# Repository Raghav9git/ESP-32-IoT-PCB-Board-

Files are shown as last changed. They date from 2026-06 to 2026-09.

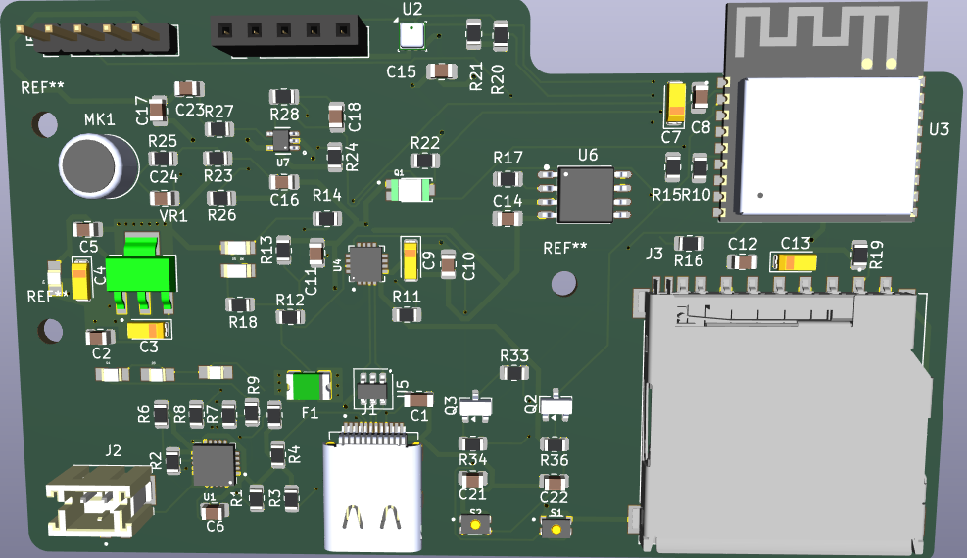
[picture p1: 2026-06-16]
3D view.png

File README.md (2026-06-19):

## ESP32-C3 IoT Sensor Development Board

A compact 4-layer IoT development board built around the ESP32-C3, integrating environmental sensing, local storage, USB-C power with LiPo battery management, and a programming/debug interface on a single board. Designed in KiCad 10.0.

This is a multi-domain hardware project that brings power electronics, mixed-signal sensor front-ends, digital interfaces, and RF-module integration together on one board — and routes them on a 4-layer stackup with dedicated power and ground planes.

## Overview

The goal of this board is a self-contained, battery-capable IoT platform: an ESP32-C3 (Wi-Fi + BLE) as the brain, surrounded by the supporting subsystems a real IoT device needs — clean regulated power, safe battery charging, local data storage, environmental sensors, and a robust USB programming path.

It was built as a deliberate skill-development project to practice end-to-end PCB design across several engineering domains in a single, non-trivial board, rather than a series of isolated single-function boards.

## Features

MCU: ESP32-C3-WROOM-02 module — Wi-Fi + Bluetooth LE
Power input: USB-C connector (power + data), with input fuse protection
Battery: LiPo battery connector with onboard charge management (MCP73871) and power-path control
Regulation: 3.3 V LDO (LM1117) for the logic rail, sourced from the 5 V USB rail
Programming/Debug: CP2102N USB-to-UART bridge with automatic boot/reset (DTR/RTS) circuit
Storage: microSD card slot (SPI) + onboard SPI flash (W25Q32)
Sensors:

BME280 — temperature, humidity, barometric pressure
TEMT6000 — ambient light
Electret microphone + MAX4466 pre-amplifier — audio/sound level

User interface: Boot and Reset buttons (with RC debounce), status LEDs, I²C OLED display header, GPIO breakout header
Debug: Test points on key SPI/SD signals
Protection: USB data-line ESD protection (USBLC6)
PCB: 4-layer design with dedicated power and ground planes

## Tech Specs

ItemDetailMicrocontrollerESP32-C3-WROOM-02 (Wi-Fi + BLE)PCB layers4 (signal / GND plane / power plane / signal)Power inputUSB-C (5 V) and LiPo batteryLogic rail3.3 V (LM1117 LDO)ChargingMCP73871 LiPo charger / power pathUSB–UART bridgeCP2102NStoragemicroSD (SPI) + W25Q32 SPI flashSensorsBME280, TEMT6000, MAX4466 mic ampInterfacesI²C, SPI, UART, GPIO headerDesign toolKiCad 10.0

## Subsystem Architecture

The board is organized as a set of interacting subsystems. Each block exists for a specific reason:

## Power & Battery Management

USB-C delivers 5 V, passed through a fuse for input protection. The MCP73871 handles LiPo charging and automatic power-path switching between USB power and battery, so the board runs from USB when connected and from battery otherwise. The LM1117 LDO derives the clean 3.3 V logic rail from the 5 V rail. Input and output decoupling capacitors sit close to the regulator for stability.

## MCU

The ESP32-C3-WROOM-02 is the core — a single-chip Wi-Fi + BLE module. It runs from the 3.3 V rail with local decoupling, and exposes the SPI, I²C, UART, and GPIO interfaces that connect to the rest of the board.

## Programming & Auto-Reset

A CP2102N USB-to-UART bridge provides the serial programming/debug interface over USB-C. The DTR/RTS auto-reset circuit (two transistors) automatically drives the EN and BOOT lines during flashing, so firmware can be uploaded without manually pressing buttons — the standard ESP programming convenience circuit. USBLC6 ESD protection guards the USB data lines.

## Storage

A microSD slot (SPI) provides removable local storage for data logging, and an onboard W25Q32 SPI flash offers fixed storage for configuration or firmware data. Test points on the SPI/SD lines allow probing during bring-up.

## Sensors (Mixed-Signal Front-Ends)

BME280 — digital environmental sensor (temperature, humidity, pressure) on the I²C/SPI bus.
TEMT6000 — analog ambient light sensor feeding an ADC input.
Electret mic + MAX4466 — an analog audio front-end; the MAX4466 amplifies the microphone signal to a usable level for the ADC.

The analog sensor front-ends are the mixed-signal portion of the design, where layout and grounding affect signal quality.

## User Interface

Boot and Reset buttons with RC debounce, status LEDs for power/operation indication, an I²C header for an OLED display, and a GPIO breakout header for expansion.

## Design Highlights

4-layer stackup with dedicated ground and power planes for clean power distribution and a solid low-impedance ground return — important on a board mixing RF, analog sensors, and digital interfaces.
Mixed-signal layout — separating noisy digital and switching activity from the analog sensor front-ends.
USB & ESD considerations — controlled USB data routing and dedicated ESD protection.
Net classes for differentiated trace widths (power vs. signal).
Test points on key debug nets for hardware bring-up.
Compact, thoughtful component placement following the power and signal flow.

## Project Status

~80% complete.

 Multi-page hierarchical schematic — complete, ERC passing
 Footprint assignment
 Component placement
 4-layer stackup and plane setup
 Routing (power and signal)
 Copper zones / ground pour
 Final silkscreen pass (labels, polarity marks, board info)
 Final DRC sign-off
 Manufacturing output (Gerbers / drill files)
 Fabrication and bring-up testing

Remaining work is finishing/polish: silkscreen cleanup, a final DRC pass, and generating manufacturing files.

## Skills Developed

This project was built to practice the full PCB workflow on a realistic, multi-domain board:

Multi-page hierarchical schematic design
Power electronics: LDO regulation, LiPo charge management, power-path design
Mixed-signal design: analog sensor front-ends alongside digital interfaces
RF module integration: ESP32-C3 placement and supporting circuitry
Digital interfaces: SPI (flash, SD), I²C (sensors, OLED), UART (programming)
USB & ESD: USB-C, USB-to-UART bridge, data-line protection
4-layer PCB layout: stackup, dedicated power/ground planes, copper zones
Net classes, trace-width selection, and DRC-driven debugging
Reading and applying datasheets for component configuration

## Tools

KiCad 10.0 — schematic capture and PCB layout
Component symbols, footprints, and 3D models sourced from KiCad libraries and standard component vendors

## References & Acknowledgments

This board was built as a learning project to develop hands-on PCB design skills across power, mixed-signal, and digital domains. The design follows and adapts a published KiCad IoT development-board reference/tutorial as a starting point, which I used to study how a complete, multi-subsystem board is architected, laid out on four layers, and prepared for manufacturing.

License

Released under the MIT License. See LICENSE for details.

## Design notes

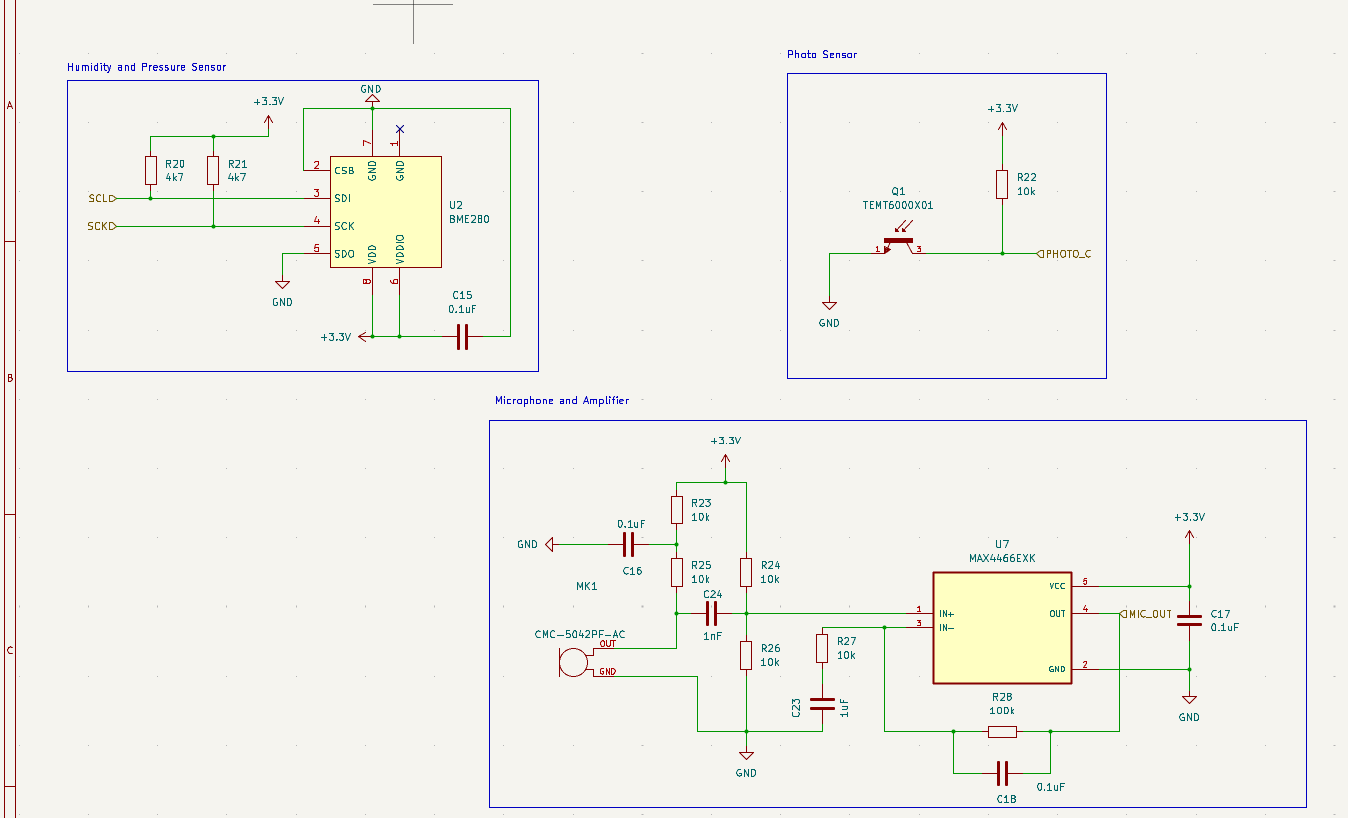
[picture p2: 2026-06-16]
Sensors.png

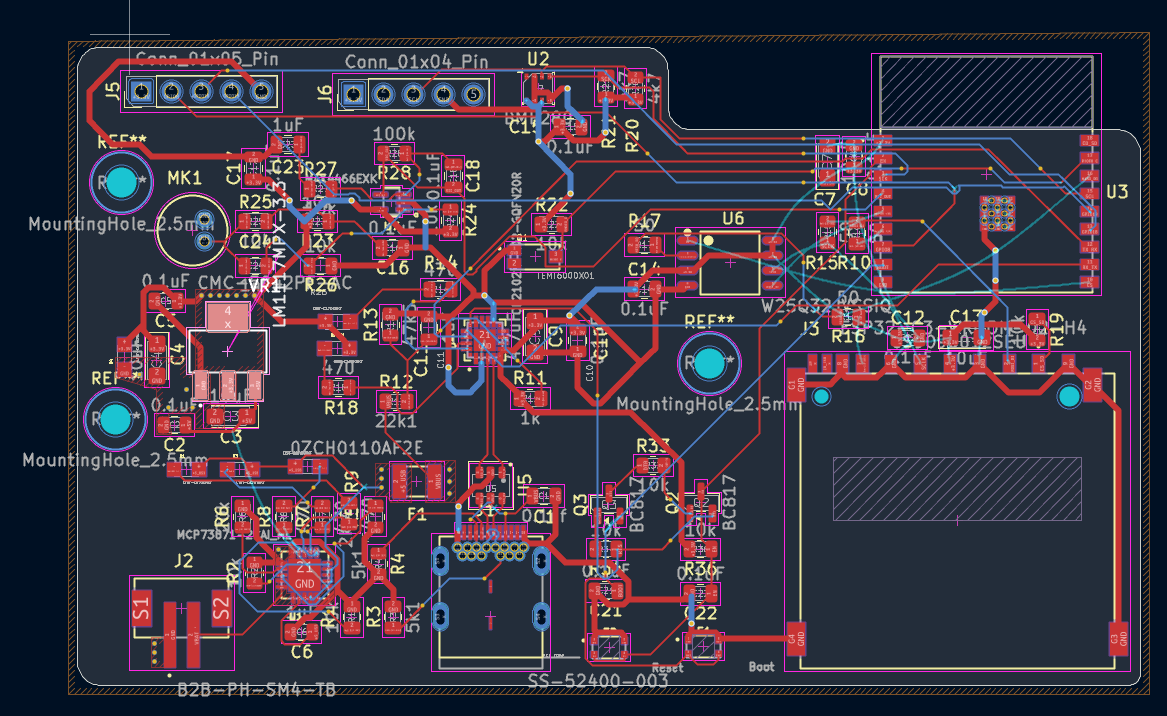
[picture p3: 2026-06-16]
PCB layout.png

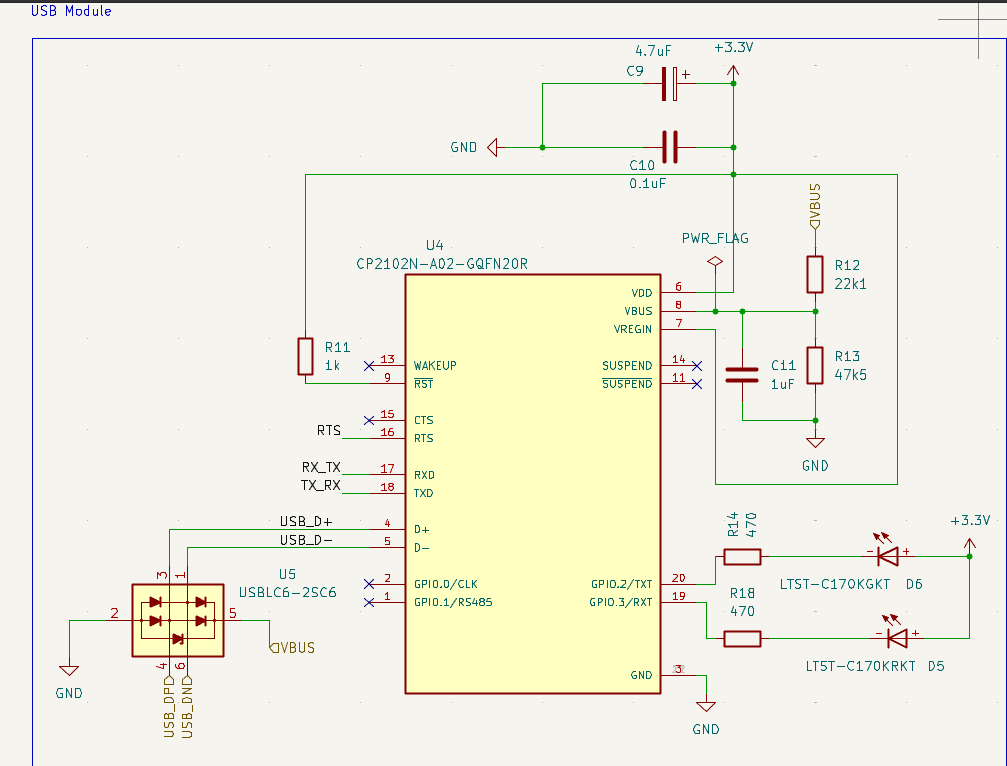
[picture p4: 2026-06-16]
Type C USB.png

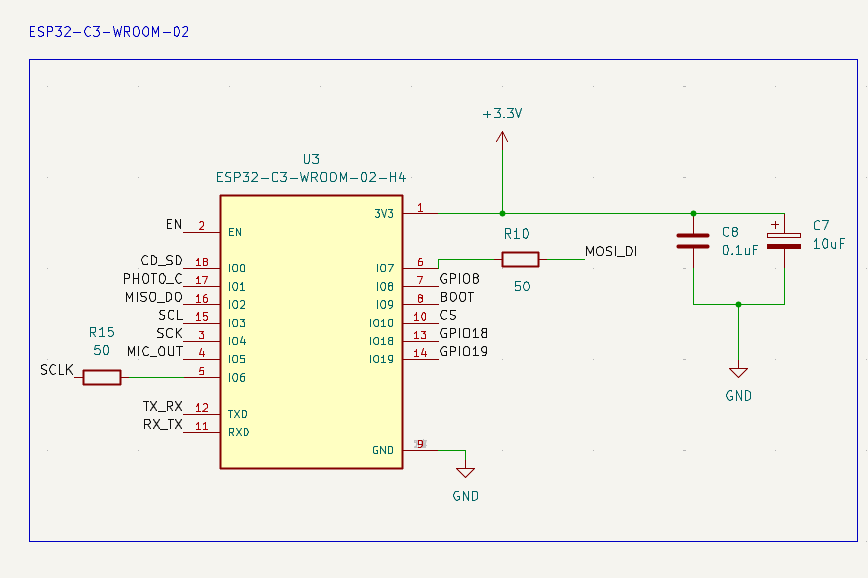
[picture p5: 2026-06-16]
ESP-32 Module.png

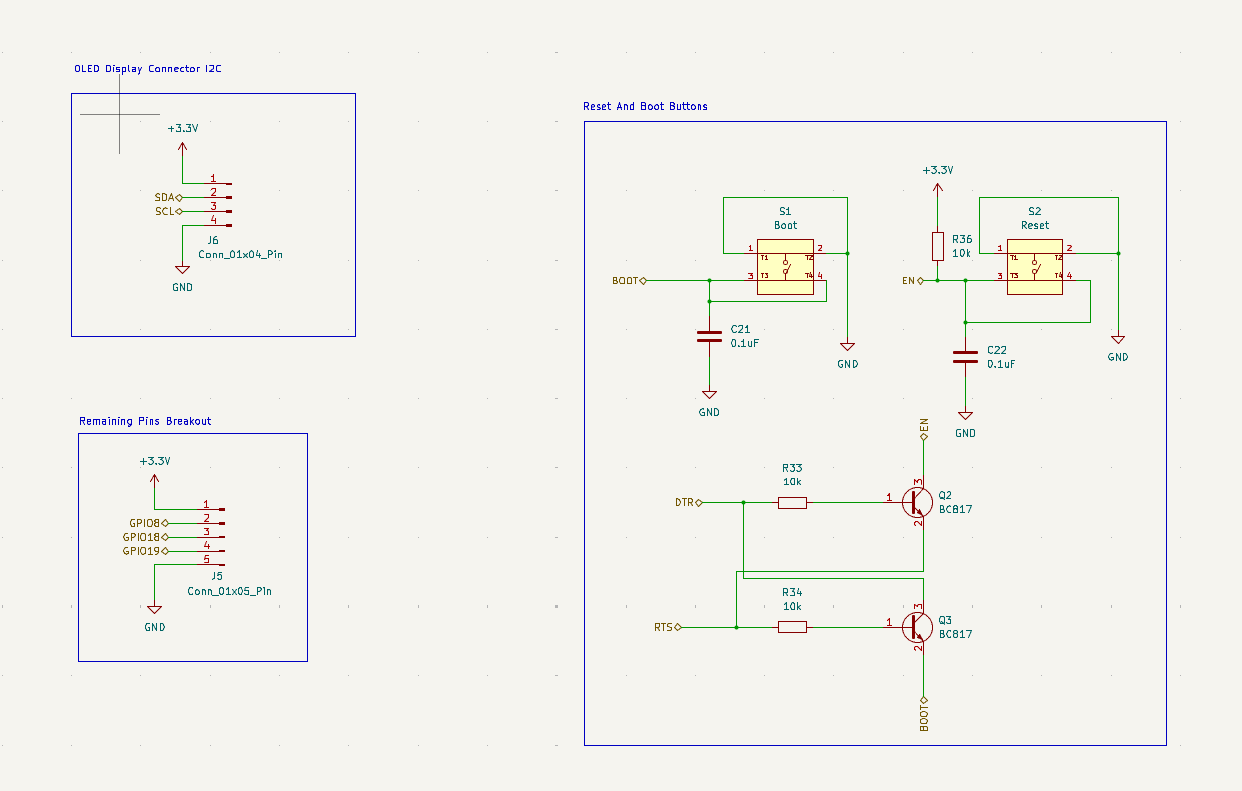
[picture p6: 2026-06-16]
User Interface.png

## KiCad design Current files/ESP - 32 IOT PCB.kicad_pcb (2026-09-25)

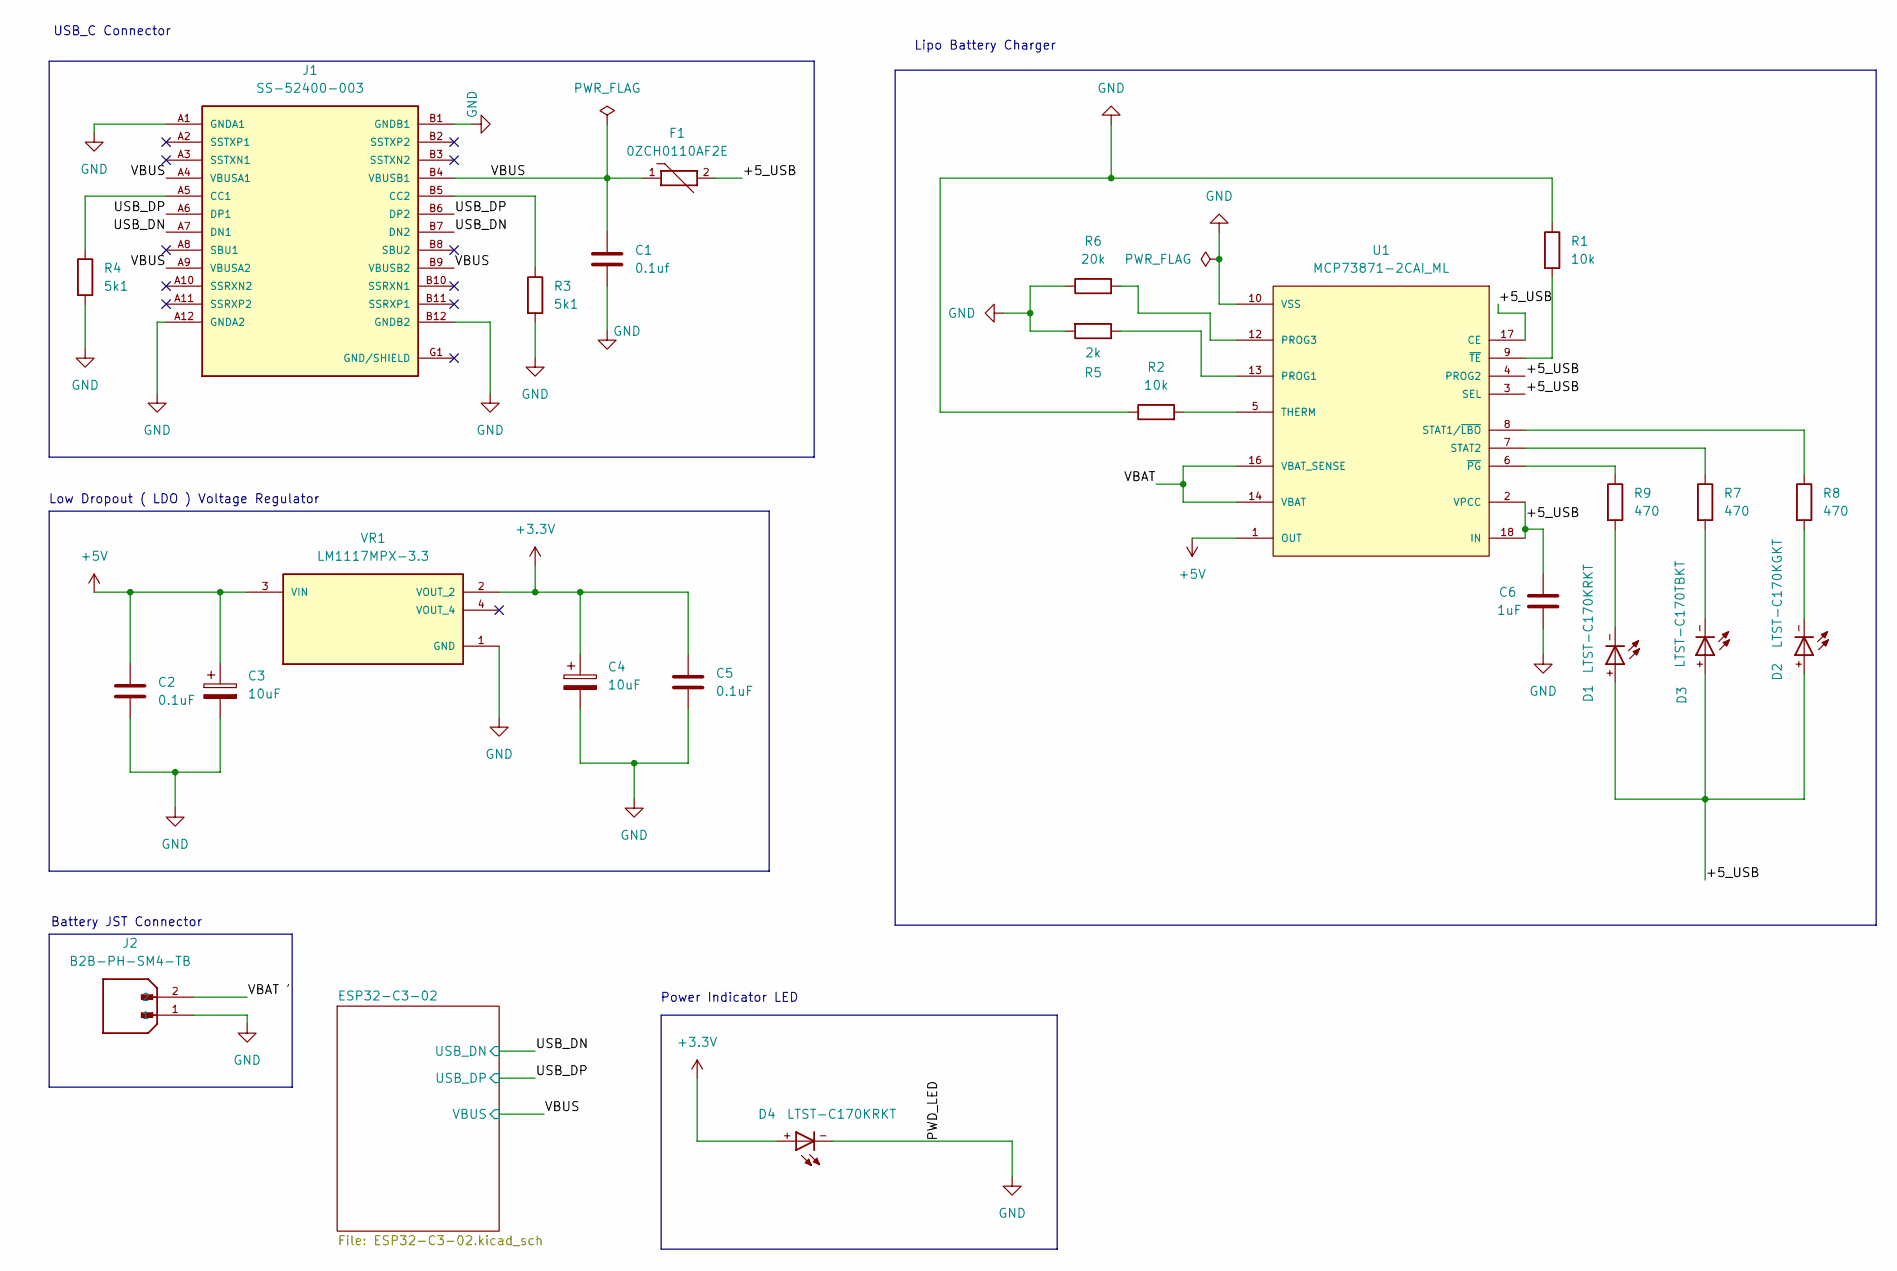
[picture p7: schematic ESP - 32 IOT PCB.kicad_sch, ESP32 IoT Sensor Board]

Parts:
C1: 0.1uf; C_0805_2012Metric
C2, C5: 0.1uF; C_0805_2012Metric
C3, C4: 10uF; CP_EIA-3216-18_Kemet-A
C6: 1uF; C_0805_2012Metric
D1, D4: LTST-C170KRKT; DIOC200X125X110
D2: LTST-C170KGKT; DIOC200X125X110
D3: LTST-C170TBKT; DIOC200X125X110
F1: 0ZCH0110AF2E; FUSC3225X100N; PARTREV Apr2023
J1: SS-52400-003; BELFUSE_SS-52400-003; PARTREV A0
J2: B2B-PH-SM4-TB; JST_B2B-PH-SM4-TB; PARTREV N/A
R1, R2: 10k; R_0805_2012Metric
R3, R4: 5k1; R_0805_2012Metric
R5: 2k; R_0805_2012Metric
R6: 20k; R_0805_2012Metric
R7, R8, R9: 470; R_0805_2012Metric
U1: MCP73871-2CAI_ML; QFN50P400X400X100-21N; PARTREV D
VR1: LM1117MPX-3.3; VREG_LM1117MPX-3.3; PARTREV O

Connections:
+3.3V: C4.1, C5.1, D4.+, VR1.2 (VOUT_2); also elsewhere on the board
+5V: C2.1, C3.1, U1.1 (OUT), U1.20 (OUT), VR1.3 (VIN)
/+5_USB: C6.1, D1.+, D2.+, D3.+, F1.2, U1.2 (VPCC), U1.3 (SEL), U1.4 (PROG2), U1.17 (CE), U1.18 (IN), U1.19 (IN)
/USB_DN: J1.A7 (DN1), J1.B7 (DN2); also elsewhere on the board
/USB_DP: J1.A6 (DP1), J1.B6 (DP2); also elsewhere on the board
/VBAT: U1.14 (VBAT), U1.15 (VBAT), U1.16 (VBAT_SENSE)
/VBAT ': J2.2
/VBUS: C1.1, F1.1, J1.A4 (VBUSA1), J1.A9 (VBUSA2), J1.B4 (VBUSB1), J1.B9 (VBUSB2); also elsewhere on the board
GND: C1.2, C2.2, C3.2, C4.2, C5.2, C6.2, D4.-, J1.A1 (GNDA1), J1.A12 (GNDA2), J1.B1 (GNDB1), J1.B12 (GNDB2), J2.1, R1.1, R2.1, R3.2, R4.2, R5.2, R6.1, U1.10 (VSS), U1.11 (VSS), U1.21 (VSS), VR1.1 (GND); also elsewhere on the board
unnamed: D1.-, R9.2
unnamed: D2.-, R8.2
unnamed: D3.-, R7.2
unnamed: J1.A5 (CC1), R4.1
unnamed: J1.B5 (CC2), R3.1
unnamed: R5.1, U1.13 (PROG1)
unnamed: R6.2, U1.12 (PROG3)
unnamed: R8.1, U1.8 (STAT1/~LBO)
unnamed: R7.1, U1.7 (STAT2)
unnamed: R2.2, U1.5 (THERM)
unnamed: R9.1, U1.6 (~PG)
unnamed: R1.2, U1.9 (~TE)

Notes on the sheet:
Lipo Battery Charger
Power Indicator LED
USB_C Connector
Battery JST Connector
Low Dropout ( LDO ) Voltage Regulator

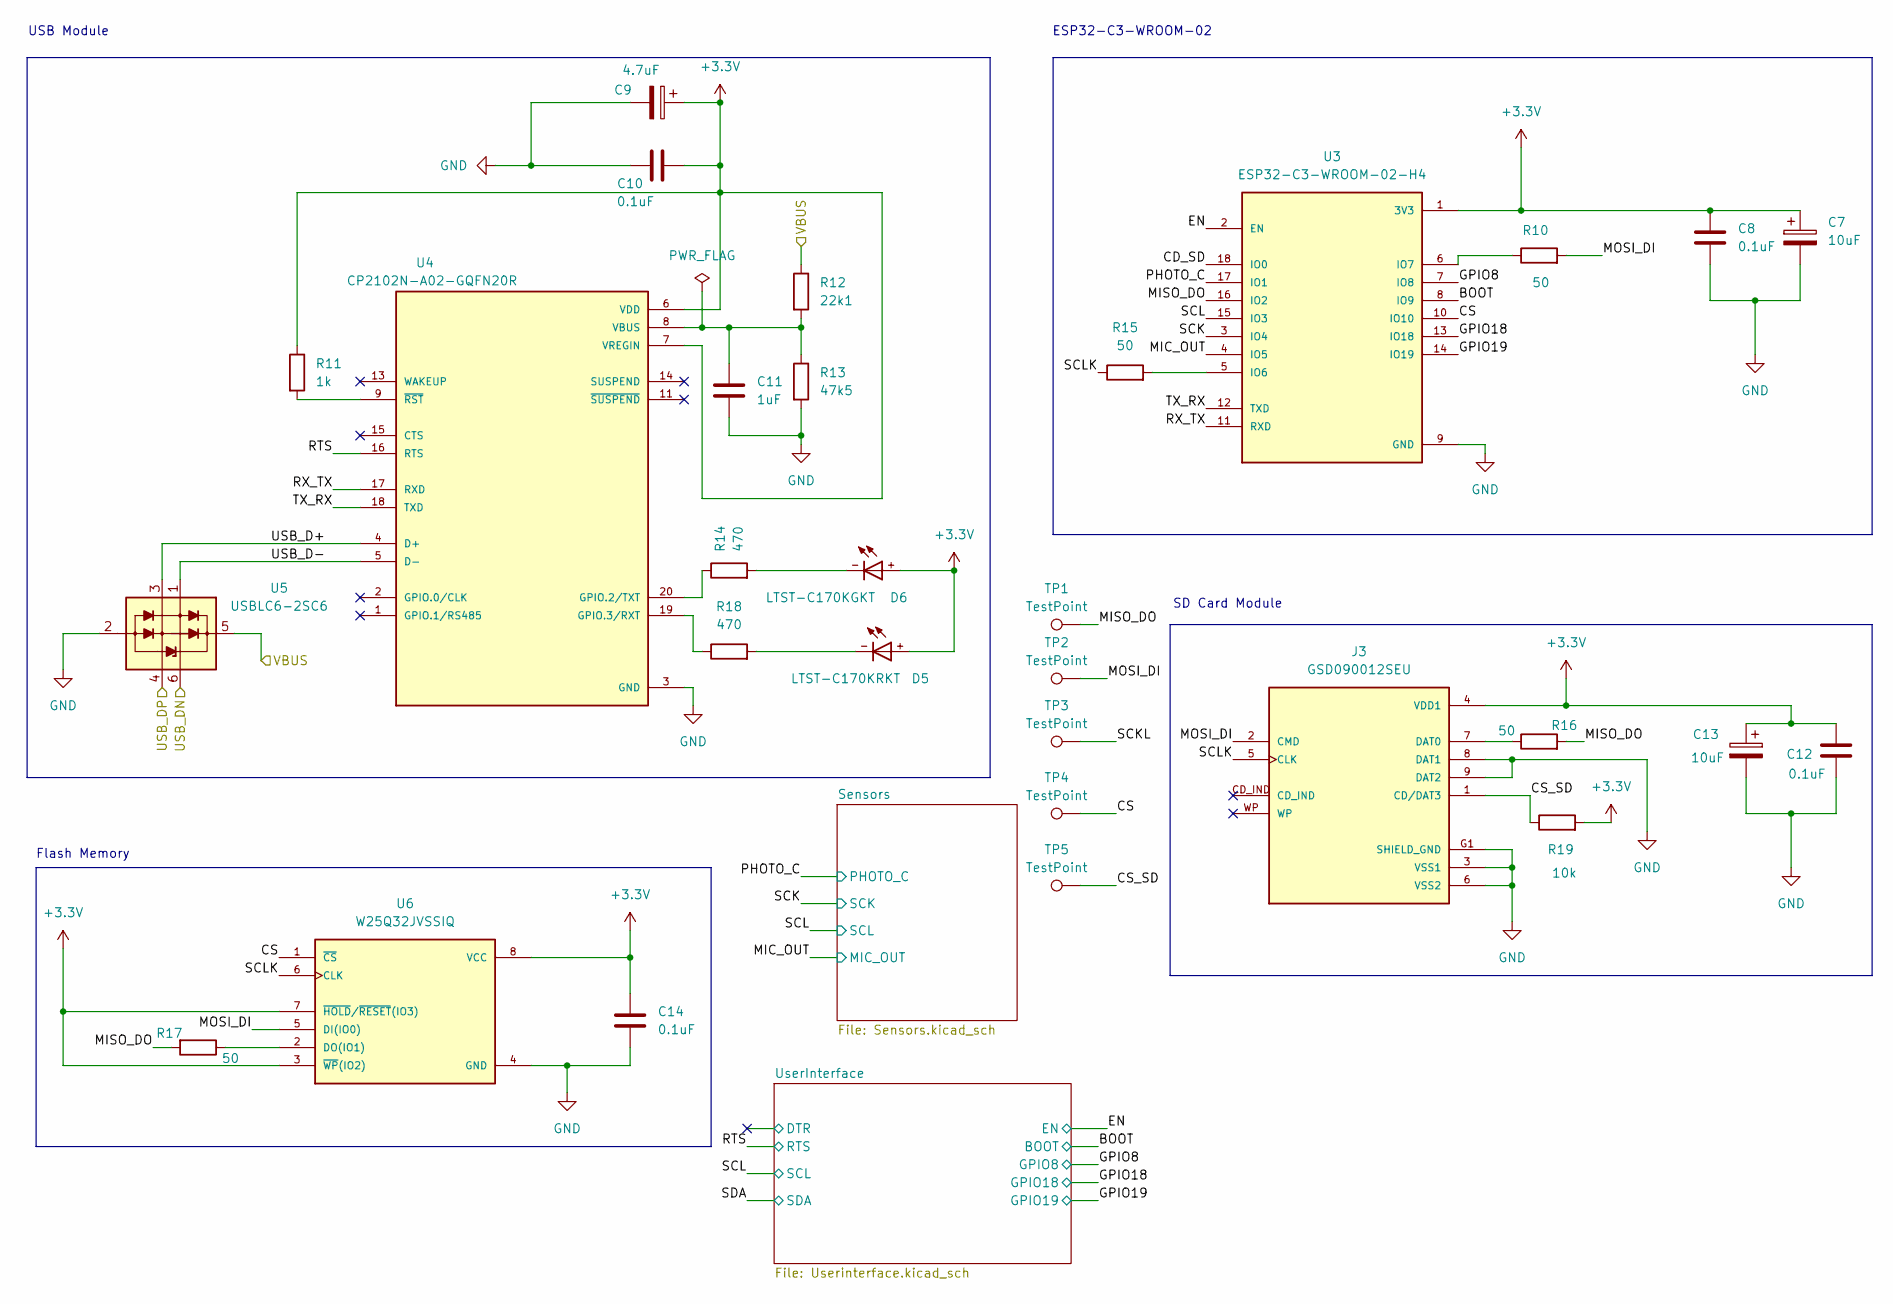
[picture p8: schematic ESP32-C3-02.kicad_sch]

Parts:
C7, C13: 10uF; CP_EIA-3216-18_Kemet-A
C8, C10, C12, C14: 0.1uF; C_0805_2012Metric
C9: 4.7uF; CP_EIA-3216-18_Kemet-A
C11: 1uF; C_0805_2012Metric
D5: LTST-C170KRKT; DIOC200X125X110
D6: LTST-C170KGKT; DIOC200X125X110
J3: GSD090012SEU; AMPHENOL_GSD090012SEU; PARTREV E
R10, R15, R16, R17: 50; R_0805_2012Metric
R11: 1k; R_0805_2012Metric
R12: 22k1; R_0805_2012Metric
R13: 47k5; R_0805_2012Metric
R14, R18: 470; R_0805_2012Metric
R19: 10k; R_0805_2012Metric
TP1, TP2, TP3, TP4, TP5: TestPoint; TestPoint_Pad_D1.0mm
U3: ESP32-C3-WROOM-02-H4; MODULE_ESP32-C3-WROOM-02-H4
U4: CP2102N-A02-GQFN20R; SILABS_CP2102N-A02-GQFN20R; PARTREV 1.3
U5: USBLC6-2SC6; SOT-23-6
U6: W25Q32JVSSIQ; SOIC127P790X216-8N; M_PART_NUMBER W25QXX

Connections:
+3.3V: C7.1, C8.1, C9.1, C10.2, C12.1, C13.1, C14.1, D5.+, D6.+, J3.4 (VDD1), R11.1, R19.2, U3.1 (3V3), U4.6 (VDD), U4.7 (VREGIN), U6.3 (~WP(IO2)), U6.7 (~HOLD/~RESET(IO3)), U6.8 (VCC); also elsewhere on the board
/ESP32-C3-02/BOOT: U3.8 (IO9); also elsewhere on the board
/ESP32-C3-02/CD_SD: U3.18 (IO0)
/ESP32-C3-02/CS: TP4.1, U3.10 (IO10), U6.1 (~CS)
/ESP32-C3-02/CS_SD: J3.1 (CD/DAT3), R19.1, TP5.1
/ESP32-C3-02/EN: U3.2 (EN); also elsewhere on the board
/ESP32-C3-02/GPIO8: U3.7 (IO8); also elsewhere on the board
/ESP32-C3-02/GPIO18: U3.13 (IO18); also elsewhere on the board
/ESP32-C3-02/GPIO19: U3.14 (IO19); also elsewhere on the board
/ESP32-C3-02/MIC_OUT: U3.4 (IO5); also elsewhere on the board
/ESP32-C3-02/MISO_DO: R16.2, R17.2, TP1.1, U3.16 (IO2)
/ESP32-C3-02/MOSI_DI: J3.2 (CMD), R10.2, TP2.1, U6.5 (DI(IO0))
/ESP32-C3-02/PHOTO_C: U3.17 (IO1); also elsewhere on the board
/ESP32-C3-02/RTS: U4.16 (RTS); also elsewhere on the board
/ESP32-C3-02/RX_TX: U3.11 (RXD), U4.17 (RXD)
/ESP32-C3-02/SCK: U3.3 (IO4); also elsewhere on the board
/ESP32-C3-02/SCL: U3.15 (IO3); also elsewhere on the board
/ESP32-C3-02/SCLK: J3.5 (CLK), R15.1, U6.6 (CLK)
/ESP32-C3-02/TX_RX: U3.12 (TXD), U4.18 (TXD)
/ESP32-C3-02/USB_D+: U4.4 (D+), U5.3 (L2)
/ESP32-C3-02/USB_D-: U4.5 (D-), U5.1 (L1)
/USB_DN: U5.6 (L1); also elsewhere on the board
/USB_DP: U5.4 (L2); also elsewhere on the board
/VBUS: R12.1, U5.5 (VP); also elsewhere on the board
GND: C7.2, C8.2, C9.2, C10.1, C11.2, C12.2, C13.2, C14.2, J3.3 (VSS1), J3.6 (VSS2), J3.8 (DAT1), J3.9 (DAT2), J3.G1 (SHIELD_GND), J3.G2 (SHIELD_GND), J3.G3 (SHIELD_GND), J3.G4 (SHIELD_GND), R13.2, U3.9 (GND), U3.19 (GND), U3.20 (GND), U3.21 (GND), U3.22 (GND), U3.23 (GND), U3.24 (GND), U3.25 (GND), U3.26 (GND), U3.27 (GND), U3.28 (GND), U3.29 (GND), U3.30 (GND), U3.31 (GND), U3.32 (GND), U3.33 (GND), U3.34 (GND), U3.35 (GND), U3.36 (GND), U3.37 (GND), U3.38 (GND), U3.39 (GND), U4.3 (GND), U4.12 (GND), U4.21 (GND), U5.2 (VN), U6.4 (GND); also elsewhere on the board
unnamed: D5.-, R18.2
unnamed: D6.-, R14.2
unnamed: J3.7 (DAT0), R16.1
unnamed: R15.2, U3.5 (IO6)
unnamed: R10.1, U3.6 (IO7)
unnamed: R14.1, U4.20 (GPIO.2/TXT)
unnamed: R18.1, U4.19 (GPIO.3/RXT)
unnamed: C11.1, R12.2, R13.1, U4.8 (VBUS)
unnamed: R11.2, U4.9 (~RST)
unnamed: R17.1, U6.2 (DO(IO1))

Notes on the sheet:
USB Module
Flash Memory
ESP32-C3-WROOM-02
SD Card Module

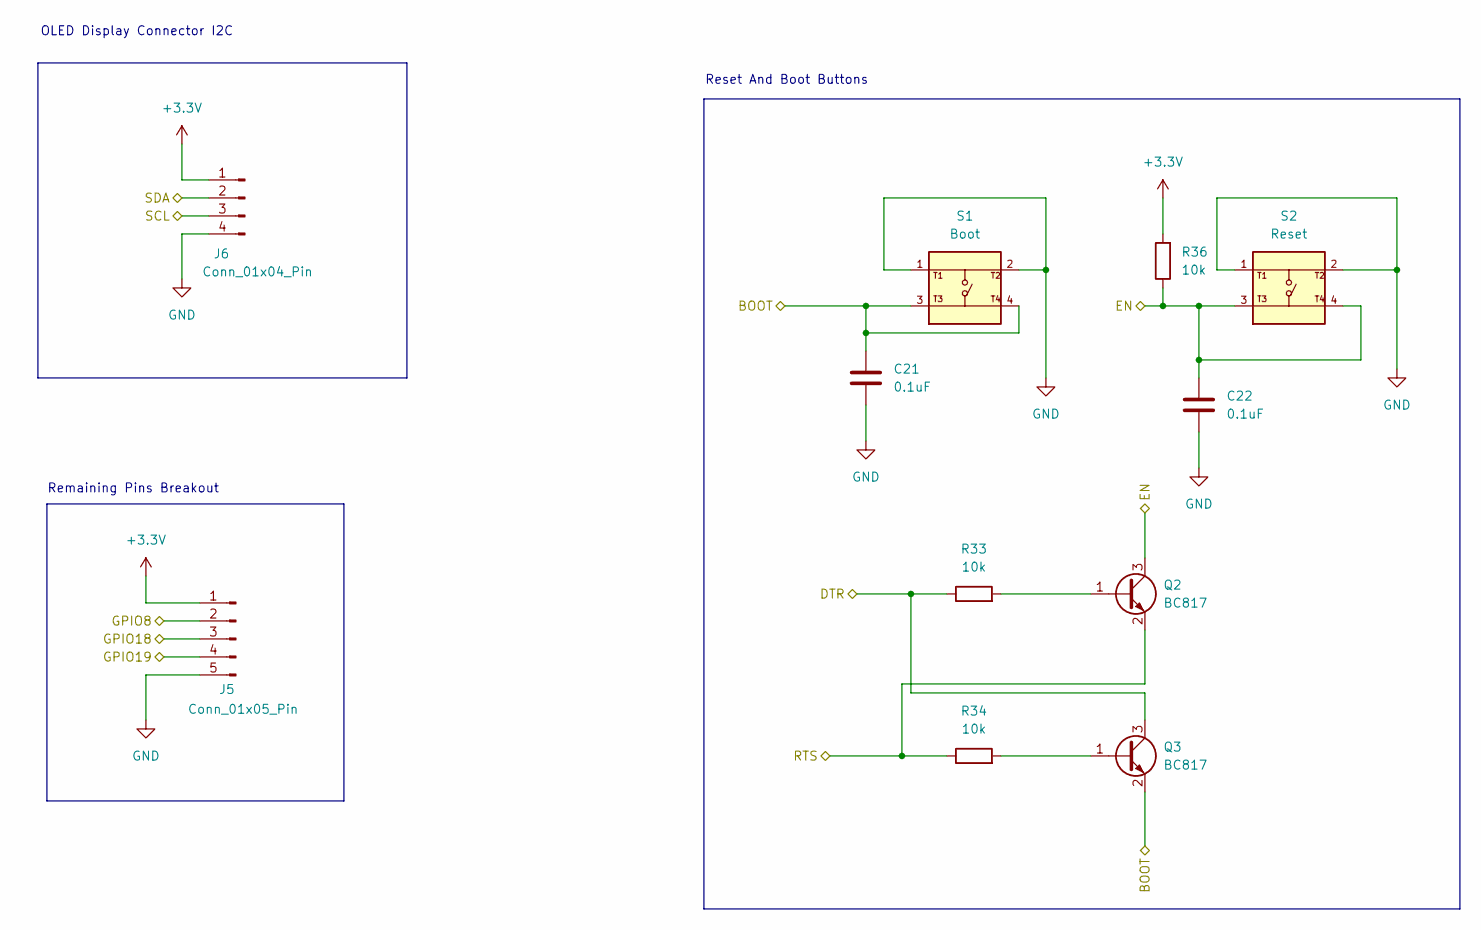
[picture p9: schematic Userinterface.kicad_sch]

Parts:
C21, C22: 0.1uF; C_0805_2012Metric
J5: Conn_01x05_Pin; PinHeader_1x05_P2.54mm_Vertical
J6: Conn_01x04_Pin; PinHeader_1x05_P2.54mm_Vertical
Q2, Q3: BC817; SOT-23
R33, R34, R36: 10k; R_0805_2012Metric
S1: Boot; SW_USLPT2819DT2TR; PARTREV P
S2: Reset; SW_USLPT2819DT2TR; PARTREV P

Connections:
+3.3V: J5.1, J6.1, R36.2; also elsewhere on the board
/ESP32-C3-02/BOOT: C21.1, Q3.2 (E), S1.3, S1.4; also elsewhere on the board
/ESP32-C3-02/EN: C22.1, Q2.3 (C), R36.1, S2.3, S2.4; also elsewhere on the board
/ESP32-C3-02/GPIO8: J5.2; also elsewhere on the board
/ESP32-C3-02/GPIO18: J5.3; also elsewhere on the board
/ESP32-C3-02/GPIO19: J5.4; also elsewhere on the board
/ESP32-C3-02/RTS: Q2.2 (E), R34.1; also elsewhere on the board
/ESP32-C3-02/SCL: J6.3; also elsewhere on the board
/ESP32-C3-02/SDA: J6.2
/ESP32-C3-02/UserInterface/DTR: Q3.3 (C), R33.1
GND: C21.2, C22.2, J5.5, J6.4, S1.1, S1.2, S2.1, S2.2; also elsewhere on the board
unnamed: Q2.1 (B), R33.2
unnamed: Q3.1 (B), R34.2

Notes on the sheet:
OLED Display Connector I2C
Reset And Boot Buttons
Remaining Pins Breakout

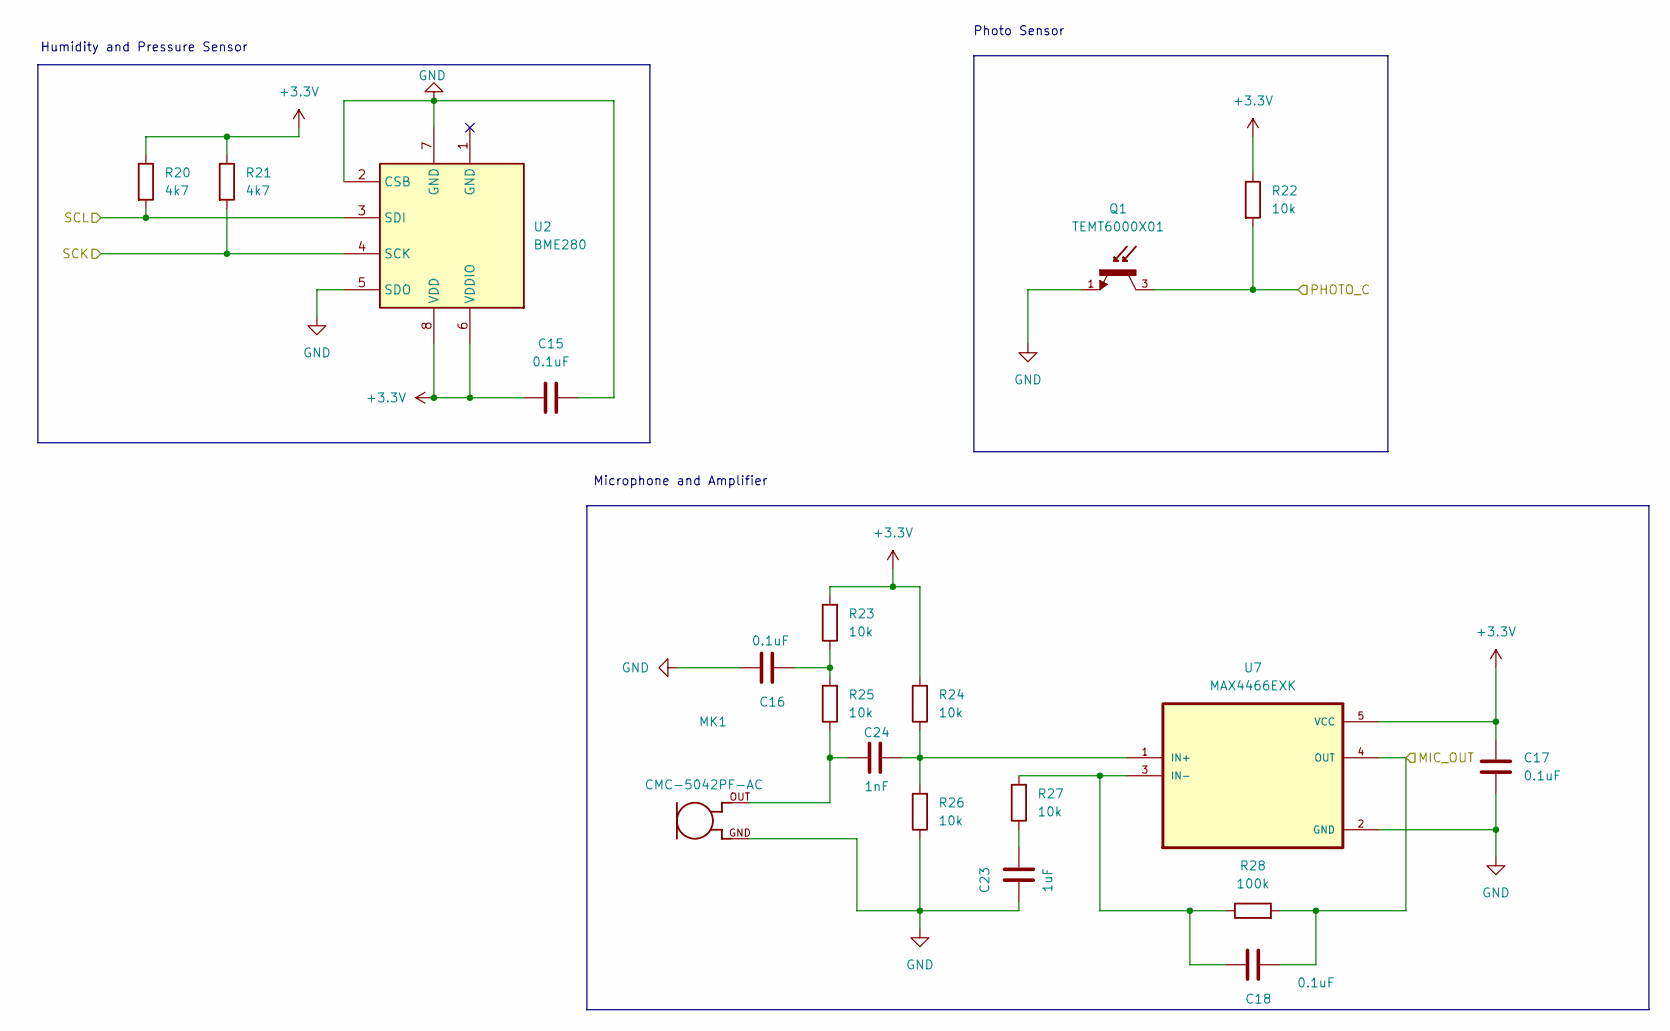
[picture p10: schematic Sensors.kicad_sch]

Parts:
C15, C16, C17, C18: 0.1uF; C_0805_2012Metric
C23: 1uF; C_0805_2012Metric
C24: 1nF; C_0805_2012Metric
MK1: CMC-5042PF-AC; CUI_CMC-5042PF-AC
Q1: TEMT6000X01; TRANS_TEMT6000X01; PARTREV 1.9
R20, R21: 4k7; R_0805_2012Metric
R22, R23, R24, R25, R26, R27: 10k; R_0805_2012Metric
R28: 100k; R_0805_2012Metric
U2: BME280; Bosch_LGA-8_2.5x2.5mm_P0.65mm_ClockwisePinNumbering
U7: MAX4466EXK; SOT65P210X110-5N

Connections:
+3.3V: C15.1, C17.1, R20.1, R21.1, R22.1, R23.2, R24.2, U2.6 (VDDIO), U2.8 (VDD), U7.5 (VCC); also elsewhere on the board
/ESP32-C3-02/MIC_OUT: C18.2, R28.2, U7.4 (OUT); also elsewhere on the board
/ESP32-C3-02/PHOTO_C: Q1.3, R22.2; also elsewhere on the board
/ESP32-C3-02/SCK: R21.2, U2.4 (SCK); also elsewhere on the board
/ESP32-C3-02/SCL: R20.2, U2.3 (SDI); also elsewhere on the board
GND: C15.2, C16.1, C17.2, C23.2, MK1.GND, Q1.1, R26.1, U2.2 (CSB), U2.5 (SDO), U2.7 (GND), U7.2 (GND); also elsewhere on the board
unnamed: C16.2, R23.1, R25.2
unnamed: C23.1, R27.1
unnamed: C24.1, MK1.OUT, R25.1
unnamed: C24.2, R24.1, R26.2, U7.1 (IN+)
unnamed: C18.1, R27.2, R28.1, U7.3 (IN-)

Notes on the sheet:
Photo Sensor
Microphone and Amplifier
Humidity and Pressure Sensor

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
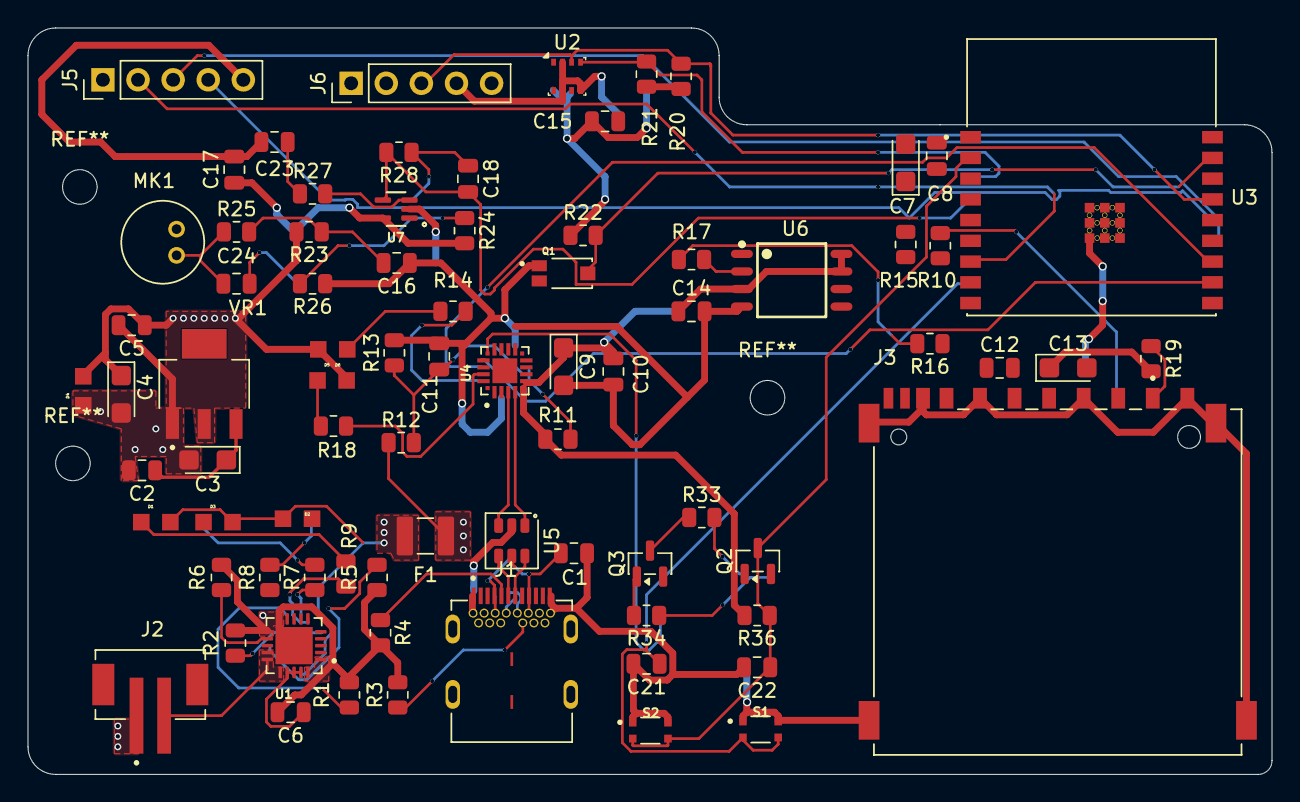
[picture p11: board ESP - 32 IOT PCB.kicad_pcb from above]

Board: 4 copper layers, 90.0 x 54.0 mm, 79 parts (0 on the bottom side), 57 nets.

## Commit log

2026-06-19 Rename Screenshot 2026-06-16 144022.png to PCB layout.png
2026-06-19 Rename Screenshot 2026-06-16 144109.png to Power Circuitry.png
2026-06-19 Rename Screenshot 2026-06-16 144512.png to Sensors.png
